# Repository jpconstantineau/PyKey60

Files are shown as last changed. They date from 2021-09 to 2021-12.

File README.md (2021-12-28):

# PyKey60 - Keyboard Hardware supported by the PyKey60 CircuitPython Download

### PyKey60: 60% Keyboard

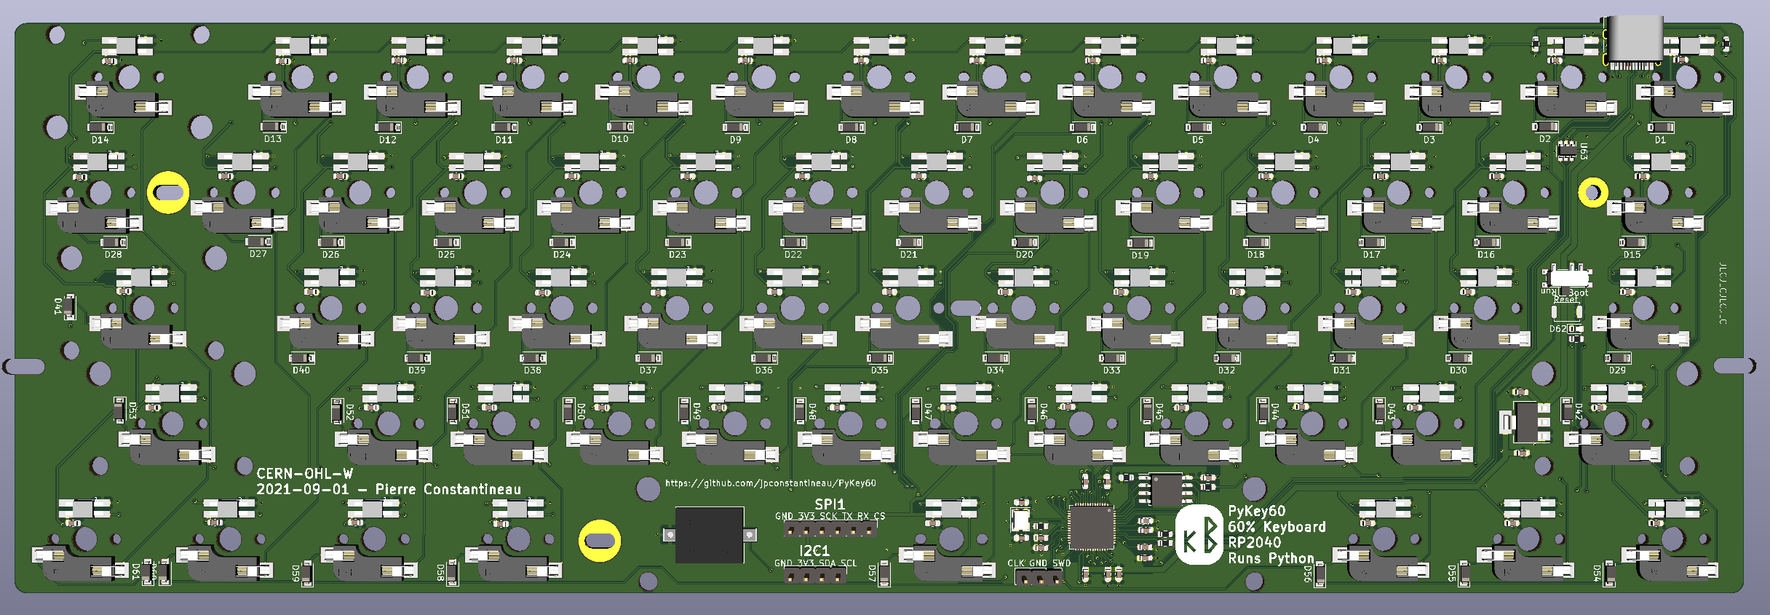
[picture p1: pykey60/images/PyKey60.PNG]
PyKey60


The PyKey60 is a custom programmable mechanical keyboard with a standard ANSI 60% keyboard layout compatible with any cases made for the GH60. The PyKey60 uses mechanical switches (Cherry MX type). The keys are hot-swap socketed and have an individual underglow RGB LED which can be turned on. The PCB was designed for use with PCB-mount stabilizers.

Since this is a Hot Swappable Switches keyboard, you can choose the MX switches as well as the keycaps you prefer. You can even mix and match switches for the ultimate customization.

Just like CircuitPython, this keyboard is targeted for beginners. The design keeps the matrix definition simple to 14 columns and 5 rows instead of using a GPIO-optimized matrix of 8 columns and 8 rows. Neopixel order is also in line with key numbers. This keeps the complexity of coding a keyboard firmware to a minimum.

[KMK Firmware](https://github.com/KMKfw/kmk_firmware/tree/master/boards/jpconstantineau/PyKey60)

Design of PyKey60 is licensed under **CERN Open Hardware Licence Version 2 - Weakly Reciprocal**

Author of the Pykey60 is Pierre Constantineau

### VColChoc44 (Atreus44)

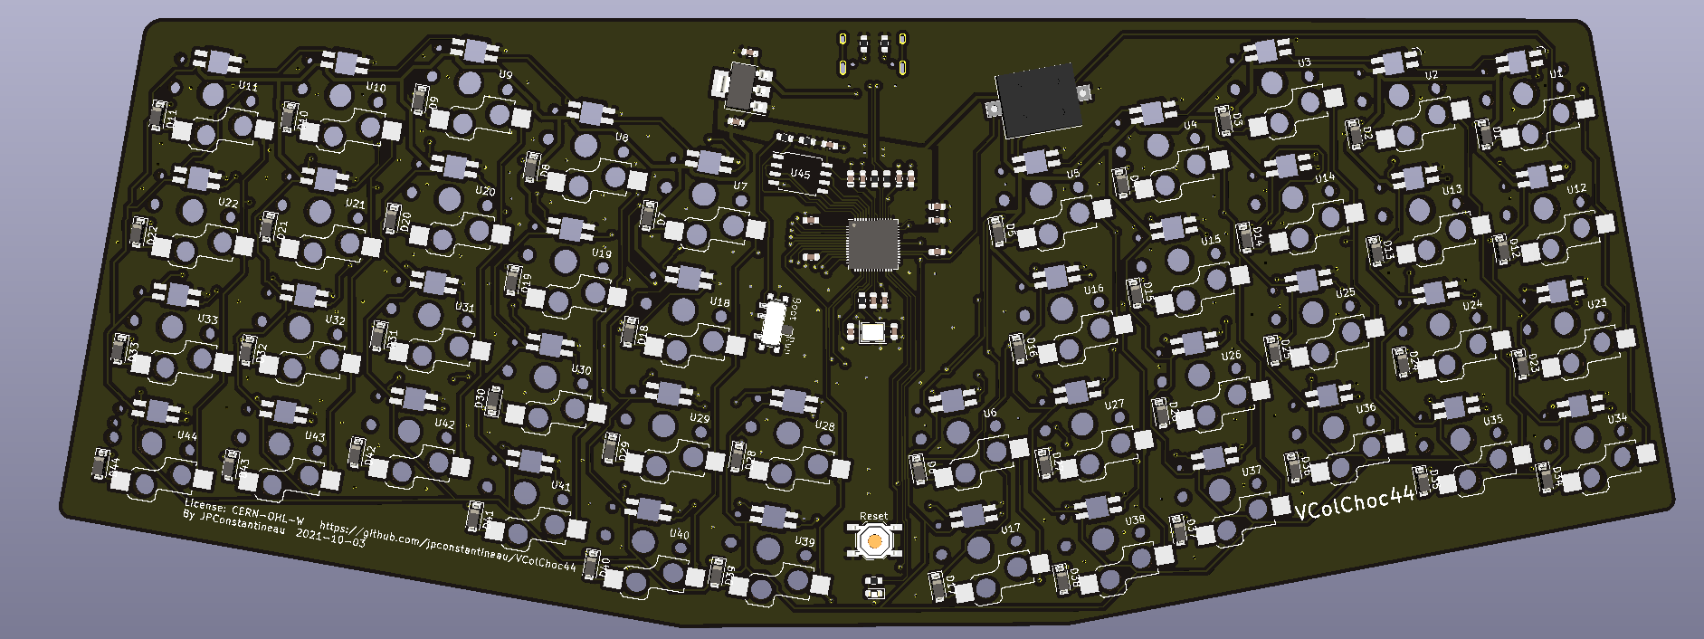
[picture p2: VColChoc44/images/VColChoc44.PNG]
VColChoc44


The VColChoc44 is a custom programmable mechanical keyboard with a 44-keys ergonomic keyboard layout. The VColChoc44 uses low profile mechanical switches (Kailh Choc V1 type). The keys are hot-swap socketed and have an individual underglow RGB LED which can be turned on.

The rows and columns used by VColChoc44 are a subset of PyKey60.

Design of VColChoc44 is licensed under **CERN Open Hardware Licence Version 2 - Weakly Reciprocal**

Author of the VColChoc44 is Pierre Constantineau

### PyKey87: TKL (Ten Key Less) Keyboard

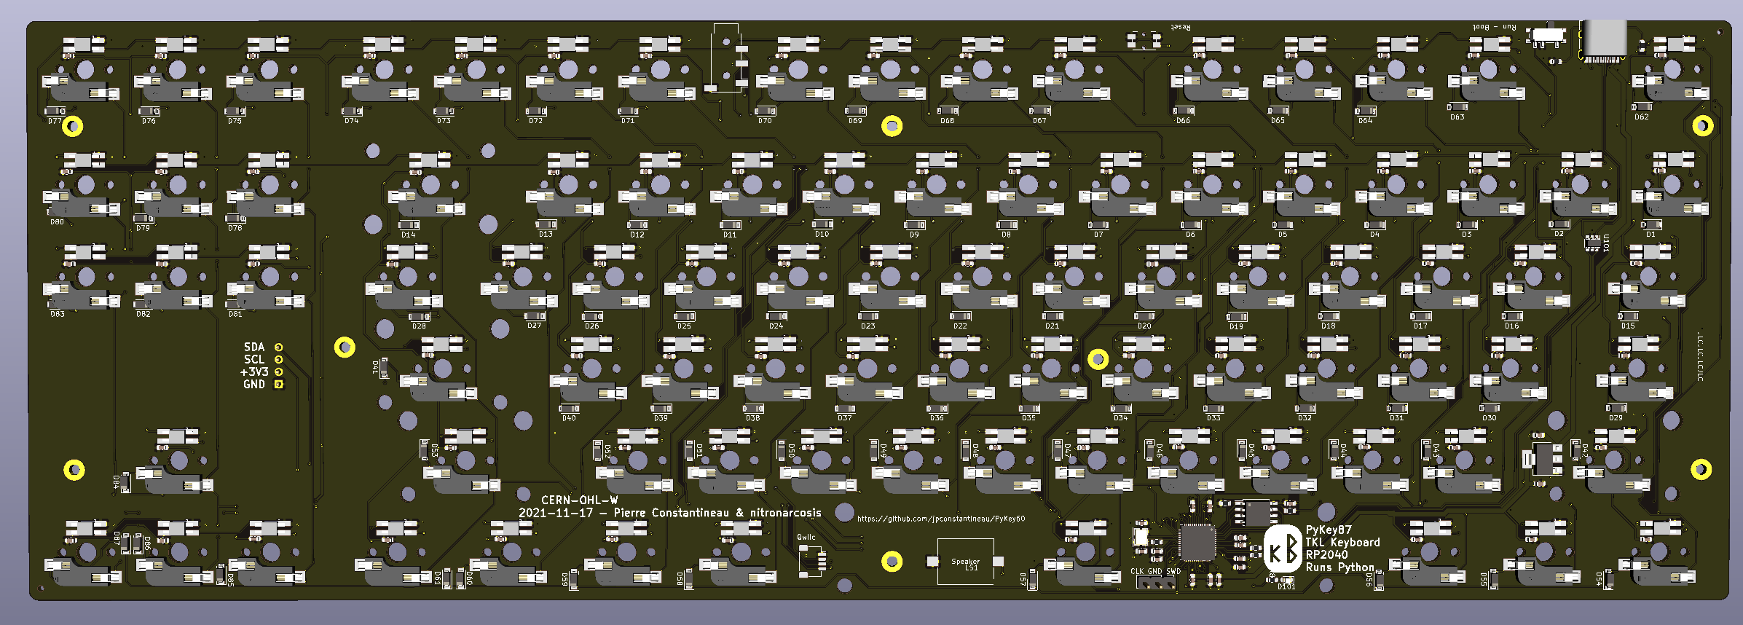
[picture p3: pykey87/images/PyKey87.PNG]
PyKey87


The PyKey87 is a custom programmable mechanical keyboard with a standard ANSI TKL (Ten Key Less) keyboard layout. The PyKey87 uses mechanical switches (Cherry MX type). The keys are hot-swap socketed and have an individual underglow RGB LED which can be turned on. The PCB was designed for use with PCB-mount stabilizers.  The case is a simple sandwich case.

The design keeps the matrix definition simple to 17 columns and 6 rows.

The rows and columns used by PyKey87 expanded the PyKey60 configuration to support more rows and columns.  The SPI pins were re-used for the additional columns/row.

Design of PyKey87 is licensed under **CERN Open Hardware Licence Version 2 - Weakly Reciprocal**

Authors of the Pykey87 are Pierre Constantineau and nitronarcosis (https://github.com/nitronarcosis)

### PyKey18: Numpad

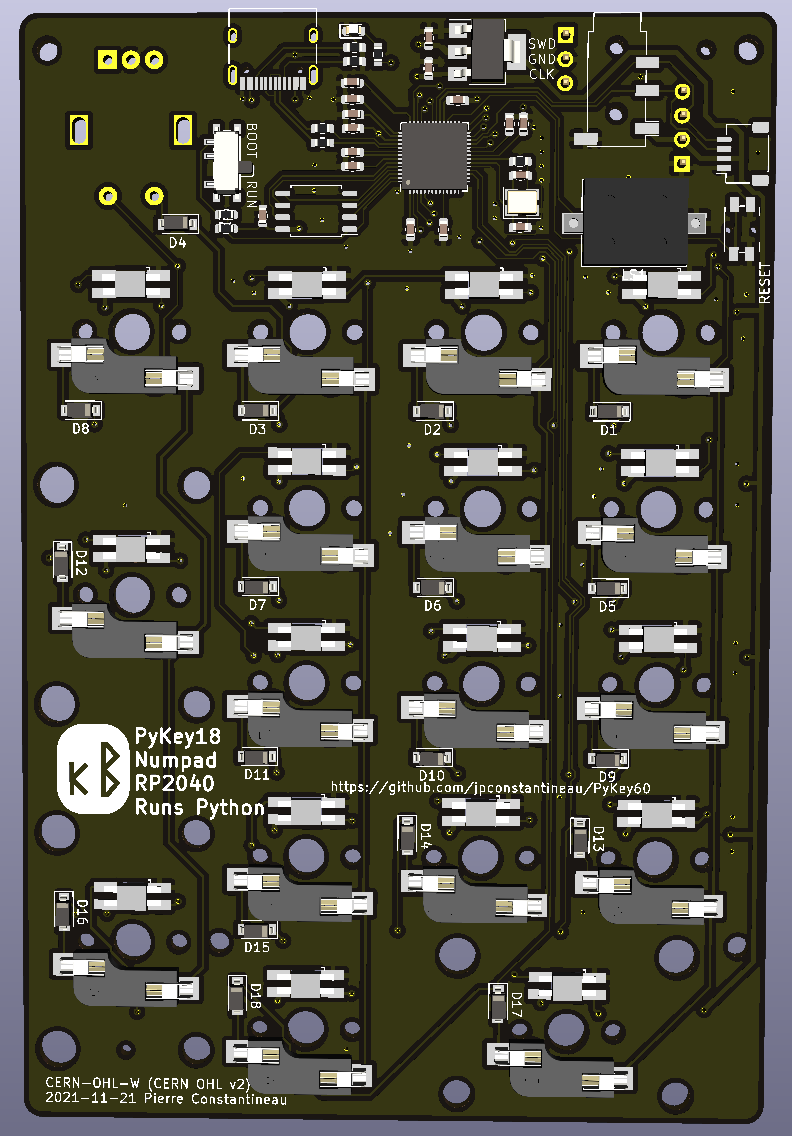
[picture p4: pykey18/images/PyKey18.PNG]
PyKey18

The PyKey18 is a custom programmable mechanical keyboard with a standard numpad keyboard layout.  The PyKey18 uses mechanical switches (Cherry MX type). The keys are hot-swap socketed and have an individual underglow RGB LED which can be turned on. The PCB was designed for use with PCB-mount stabilizers.  The case is a simple sandwich case. 

In addition to the standard numpad, it allows for a rotary encoder as well as a 0.91" OLED screen.  As such,  it can be used similarly to the Adafruit Macropad RP2040 but has more keys.

### Guidelines for adding new boards to PyKey60 repository

* Schematic must be compatible with the original Pykey60.  This means the following:
  * GPIO for Rows and Columns must remain the same
  * GPIO for RGB LEDs, Red LED and Speaker must remain the same
  * Flash chip must remain the same: W25Q128JVS
  * Schematic title block updated with correct information
    * Author(s)
    * Date
* Schematic is provided as a pdf file
* PCB Design has updated author(s) and date.
* PCB Design keeps the license label.
* Images provided in the image folder
* Both PCB-Design and PCB-Gerbers are provided.
* A readme is included
* CircuitPython must be able to run with the Original [PyKey60 CircuitPython Download/UF2](https://circuitpython.org/board/jpconstantineau_pykey60/) or the Pykey87 for larger keyboards.
* A summary description is provided in the repository readme

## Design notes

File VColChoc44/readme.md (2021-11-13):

# VColChoc44

### What is VColChoc44?

VColChoc44

### How do I build it?

You don't need many tools to build it!  
* Press the switches through the top plate
* Align the key switch pins with their sockets and press them in, 
* Install the keycaps
* Install the adhesive rubber bump ons as feet.

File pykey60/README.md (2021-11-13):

# PyKey60

### What is PyKey60?

PyKey60

### How do I build it?

You don't need many tools to build it!  
* Press the switches through the top plate
* Align the key switch pins with their sockets and press them in, 
* Install the keycaps
* Install the adhesive rubber bump ons as feet.

### How do I program it?

PyKey60 can be programmed with CircuitPython.  To get started, get the latest download from the official [CircuitPython.org](https://circuitpython.org/) site, put the RP2040 in  booloader mode by pressing "reset" while pressing the "boot" button and drag/drop in the UF2 file you just downloaded. You are now ready to program it! No build tools required on your computer!

Notes: 
* CircuitPython is licensed under the [MIT License](https://github.com/adafruit/circuitpython/blob/main/LICENSE).
* Default Firmware for PyKey60 is based on the [MACROPAD Hoykeys](https://learn.adafruit.com/macropad-hotkeys) example for the [Adafruit Macropad RP2040](https://learn.adafruit.com/adafruit-macropad-rp2040) which is part of the [Adafruit Learning System Guides](https://learn.adafruit.com/), licensed under the [MIT License](https://github.com/adafruit/Adafruit_Learning_System_Guides/blob/main/LICENSE).
* Default firmware is **MIT** licensed.

### Hardware License

Design of PyKey60 is licensed under **CERN Open Hardware Licence Version 2 - Weakly Reciprocal**

See license.txt for more details. See this [FAQ](https://ohwr.org/project/cernohl/wikis/faq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) for more information on this license.

### Licenses from reference material and libraries

|  Item  | Description | Source  | License  |
|----|---- | :-----  | :--- |
| RP2040 Hardware Design Guide  | RP2040 Documentation (for reference) | [link](https://datasheets.raspberrypi.org/rp2040/hardware-design-with-rp2040.pdf) | CC BY-ND |
| RP2040 Minimal Design Example | Kicad Project | [link](https://datasheets.raspberrypi.org/rp2040/Minimal-KiCAD.zip) | 3-Clause BSD (considered as source code included as part of documentation) |
| kicad libraries | Core libraries from Kicad | [link](https://www.kicad.org/libraries/license/) | CC-BY-SA 4.0 (with exception)|
| kicad libraries | switch symbols and footprints | [link](https://github.com/sszczep/kicad-libraries)| MIT | 

### openmoko-usb-oui application details

[USB PID Request](https://github.com/openmoko/openmoko-usb-oui)

1. () Have a README[.txt|.md] file describing which part is under which license this will help to quickly identify the project's license, particularly when several licenses are combined, or your are using libraries under other licenses. Also make sure the combination is allowed by the individual licenses.
2. (done) Include all full text licenses in a LICENSE[.txt] file
3. () Include a copyright notice in the schematic sheet(s), including author and date this will determine who the copyright holder is, and when the copyright will expire.
4. () Include the license name in the schematic sheet(s) this becomes important when different license are combined, and parts of the project, or libraries, are under different licenses
5. () Include all schematic symbols and board footprint libraries in the project without that the project can't be seen as complete. Also ensure their license is compatible.
66. () Export the schematic capture as pdf, and board layout as gerber+NC drill [and other fabrication output] files - not every user can, or wants, to install the EDA suite you are using. This is even more important if in the future this suite stops supporting the current format. If you don't want to mix the fabrication output with the source files, have a general project page pointing to the source files and fabrication output.

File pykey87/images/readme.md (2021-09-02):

These svg images were generated using the gerbers and [Tracespace View](https://tracespace.io/view/) an online gerver viewer and are for reference.

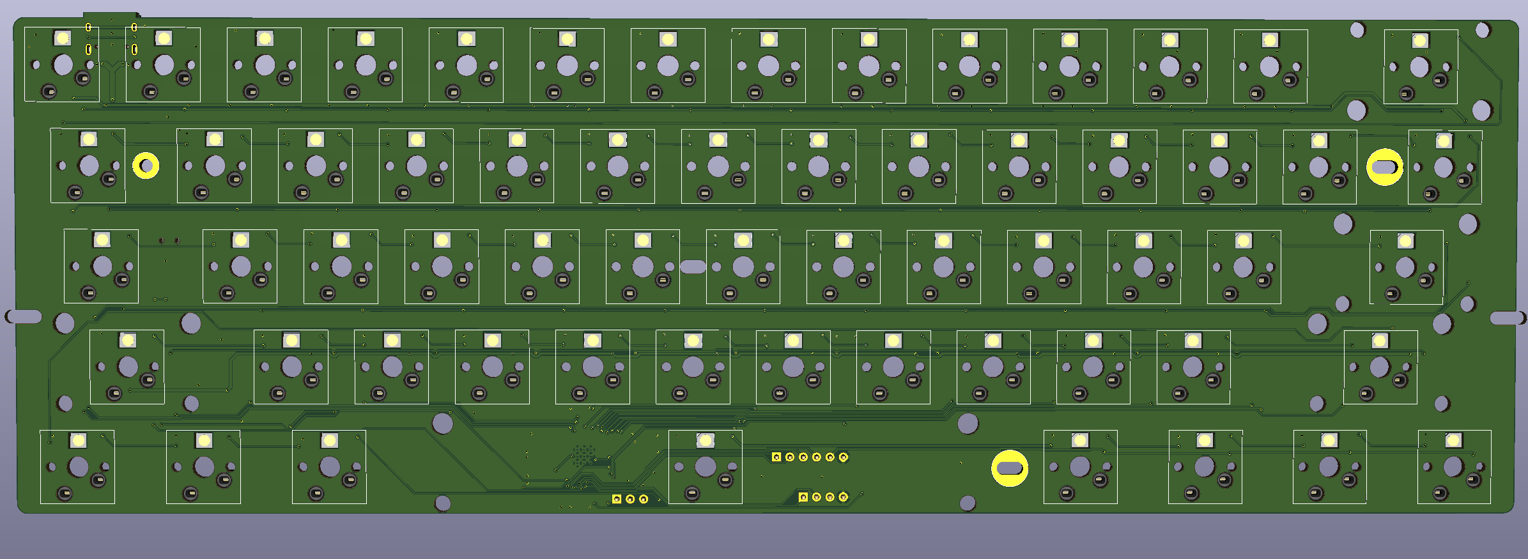
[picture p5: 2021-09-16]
pykey60/images/PCB-Front.PNG

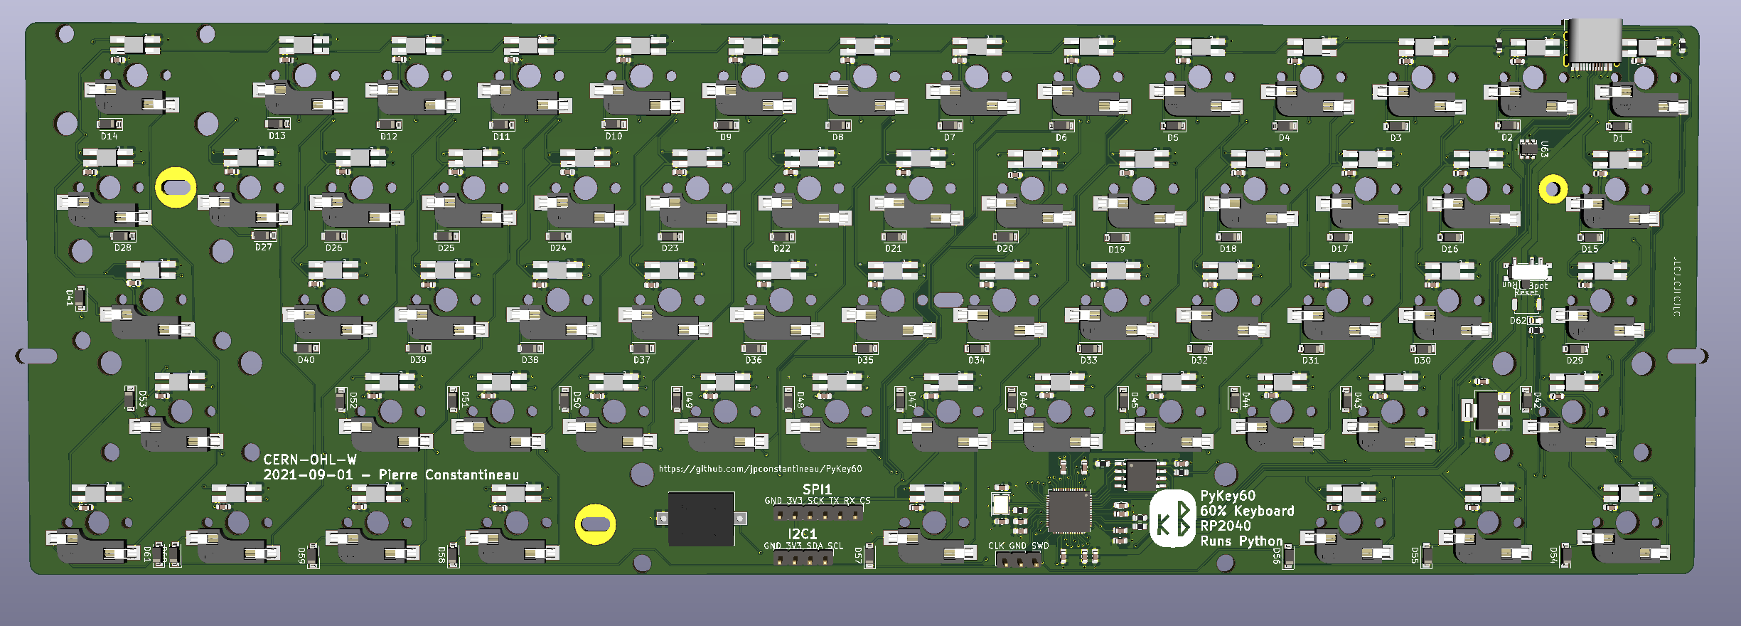
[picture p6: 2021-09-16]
pykey60/images/PCB-Back.PNG

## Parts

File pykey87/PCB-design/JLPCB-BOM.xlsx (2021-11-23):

Comment | Designator | Footprint | JLCPCB Part #
1k | R8,R7,R5 | R_0603_1608Metric | C21190
RED | D101 | LED_0603_1608Metric | C2286
100n | C9,C87,C86,C85,C84,C82,C79,C81,C83,C80,C78,C77,C76,C75,C74,C73,C72,C71,C70,C69,C68,C67,C66,C64,C65,C63,C62,C15,C23,C24,C11,C35,C10,C14,C22,C12,C21,C34,C36,C13,C19,C3,C32,C20,C37,C38,C8,C47,C4,C18,C33,C25,C48,C49,C7,C45,C2,C17,C46,C26,C50,C57,C1,C29,C5,C27,C44,C53,C39,C51,C6,C55,C61,C43,C41,C58,C59,C16,C28,C41,C60,C52,C30,C54,C40,C31,C56,C101,C96,C95,C94,C93,C92,C91,C90,C89,C88 | C_0603_1608Metric | C14663
D | D87,D86,D85,D84,D83,D82,D81,D80,D79,D78,D77,D76,D75,D74,D73,D72,D71,D70,D69,D68,D67,D66,D65,D64,D63,D62,D61,D60,D59,D58,D57,D56,D55,D54,D53,D52,D51,D50,D49,D48,D47,D46,D45,D44,D43,D42,D41,D40,D39,D38,D37,D36,D35,D34,D33,D32,D31,D30,D29,D28,D27,D26,D25,D24,D23,D22,D21,D20,D19,D18,D17,D16,D15,D14,D13,D12,D11,D10,D9,D8,D7,D6,D5,D4,D3,D2,D1 | D_SOD-123 | C81598
AMS1117-3.3 | U103 | SOT-223-3_TabPin2 | C6186
22u | C103,C102 | C_0603_1608Metric | C12891
12MHz | Y1 | Crystal_SMD_3225-4Pin_3.2x2.5mm | C9002
22 | R4,R3 | R_0603_1608Metric | C23345
22p | C100,C99 | C_0603_1608Metric | C1653
1u | C98,C97 | C_0603_1608Metric | C15849
USB_C_Receptacle_USB2.0 | J1 | USB_C_Receptacle_HRO_TYPE-C-31-M-12 | C165948
5.1k | R1,R2 | R_0603_1608Metric | C23186
RP2040 | U100 | RP2040-QFN-56 | C2040
USBLC6-2SC6 | U101 | SOT-23-6 | C2827654
W25Q128JVS | U102 | SOIC-8_5.23x5.23mm_P1.27mm | C97521
SW_SPDT | SW2 | SW_SPDT_PCM12 | C221841

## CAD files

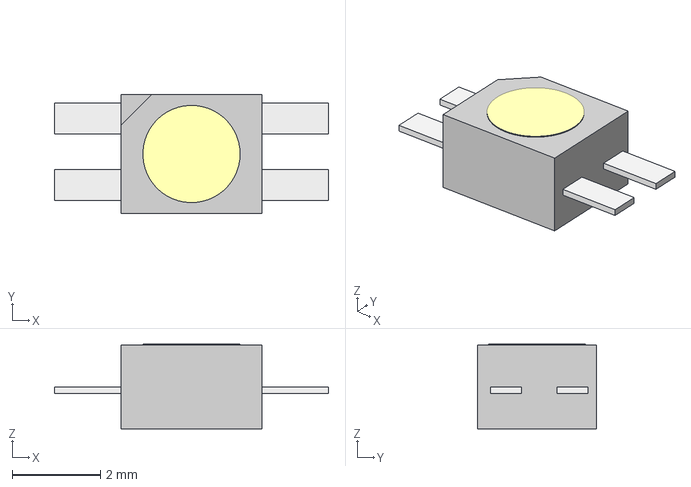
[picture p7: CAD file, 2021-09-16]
pykey18/bottom-plate/PyKey18/models/LTST-A683CEGBW.step
6.20 x 2.70 x 1.92 mm

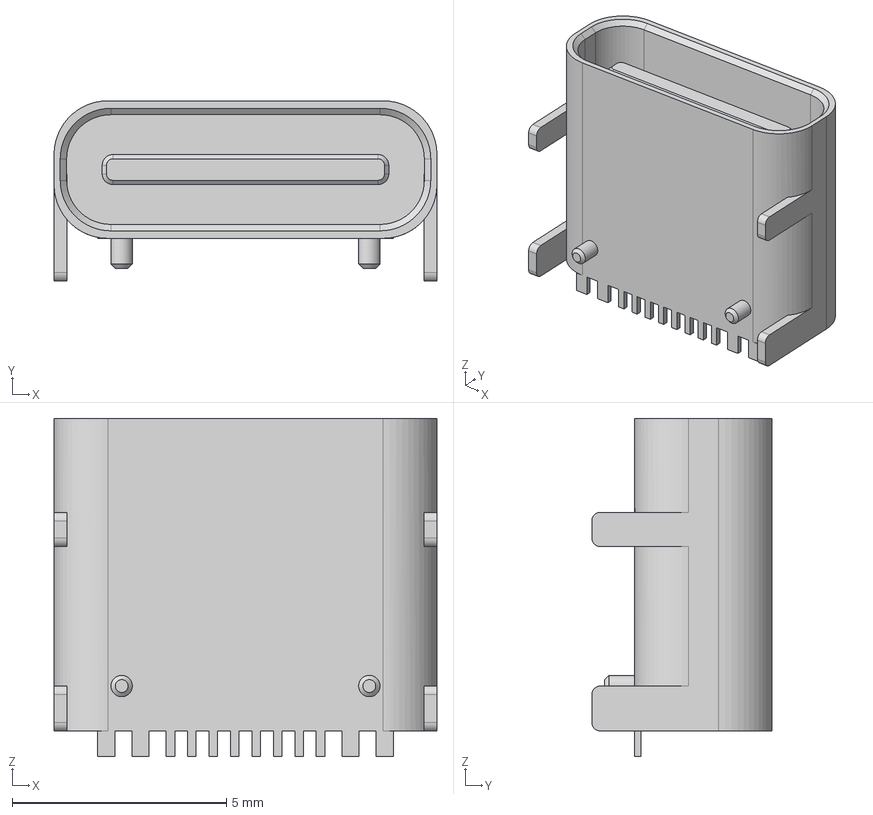
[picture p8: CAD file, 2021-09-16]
pykey18/bottom-plate/PyKey18/models/HRO TYPE-C-31-M-12.step
8.94 x 4.21 x 7.90 mm

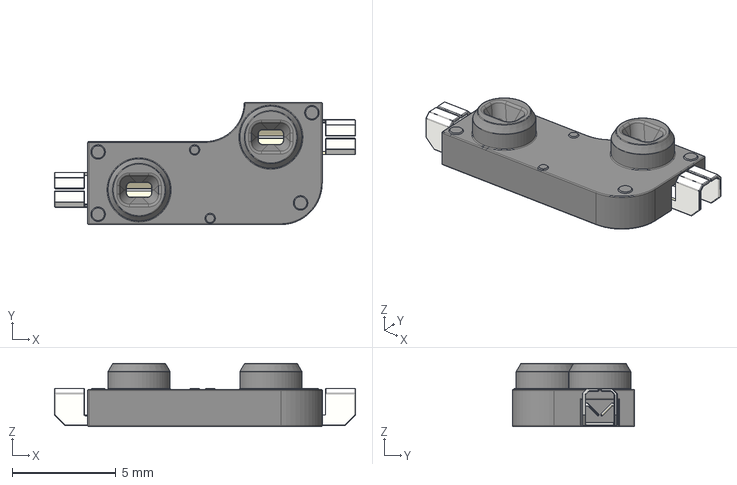
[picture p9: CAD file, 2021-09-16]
pykey18/switch-plate/PyKey18/models/KailhSocket.stp
14.5 x 5.89 x 3.05 mm

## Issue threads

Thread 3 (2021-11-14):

Add TKL Board: PyKey87

jpconstantineau, 2021-11-14:
Proposed changes:

## Schematic:
* ~~Add connector for OLED (currently not linked to schematic)~~
* ~~Add text to indicate difference between OLED and Qwiic connectors~~
* ~~Add mounting holes (JLCPCB tooling holes) (currently not linked to schematic)~~
* ~~Add TRRS connector for supporting separate numpad through I2C. Use:~~
    * Symbol: Connector:AudioJack4
    * footprint: Connectors:PJ320D_3.5mm_Jack
    * T - VCC
    * S - GND
* ~~Update date in title block~~

## PCB:
* ~~Move LED and resistor near the bottom (below the KB logo)~~
* ~~Move Run/Boot text on silkscreen near slider switch~~
* ~~Move reset text on silkscreen near reset switch~~
* ~~Label JST connector with "Qwiic"  (We can't label it Stemma as we don't support 5V).  The official logo can be used.~~
* ~~Label pins of OLED connector on back side~~
* ~~Hide labels U62-U87 on top side of PCB~~
* ~~Position new TRRS connector in line with OLED near the right edge (on the bottom side.)~~

### Stemma QT vs Qwiic
https://www.sparkfun.com/qwiic
https://learn.adafruit.com/introducing-adafruit-stemma-qt/technical-specs

@nitronarcosis

jpconstantineau, 2021-11-14:
Updates:

Getting this error message:
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

jpconstantineau, 2021-11-18:
## PCB
Diodes D62 to D77 have a similar (but easier to solve) clearance issue
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

##Schematic
There are 3 schematic symbols that are in the rescue symbol libraries.  They should point to the correct libraries so that the rescue one can be deleted.

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

USBLC602SC6 should be Power_Protection:USBLC6-2SC6e
USB_C_Receptable_USB2 should be Connector:USB_C_Receptacle_USB2.0
W25Q128JVS should be Memory_Flash:W25Q128JVS

jpconstantineau, 2021-11-18:
Useful app for checking gerbers: https://tracespace.io/view/

jpconstantineau, 2021-11-18:
## Switch Plate:

Big hole is on the side of the wire: see here:
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

## Schematic
Delete PyKey87-rescue.lib and PyKey87-rescue.dcm as they are no longer needed.

jpconstantineau, 2021-11-20:
## Schematic

* Remove reference to rescue library in project preferences:

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

Closed 2021-11-23.

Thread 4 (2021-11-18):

Add Numpad Board: PyKey18

jpconstantineau, 2021-11-18:
* RP2040 on board
* TRRS to connect to PyKey87
* OLED
* Rotary Encoder  - 1 key
* Standard Numpad layout
* Per-key RGB
* Hot Swap Sockets
* Same height as PyKey87
* Feet positions: same distance from bottom
* Standard numpad layout as per http://www.keyboard-layout-editor.com/  17 keys
* Use GPIO 27/28 for EncA/B

nitronarcosis, 2021-11-23:
I'm a little wary of running speaker in parallel to reset but that's probably not a big deal because any induced current will drive it high, not low.
I also don't see any decoupling capacitors on the LEDs.
Is there ESD protection? I'm not seeing that either.

jpconstantineau, 2021-11-24:
Added a grounded line between most of the Reset and Speaker lines
Added caps
Added ESD protection.

Closed 2021-11-23.

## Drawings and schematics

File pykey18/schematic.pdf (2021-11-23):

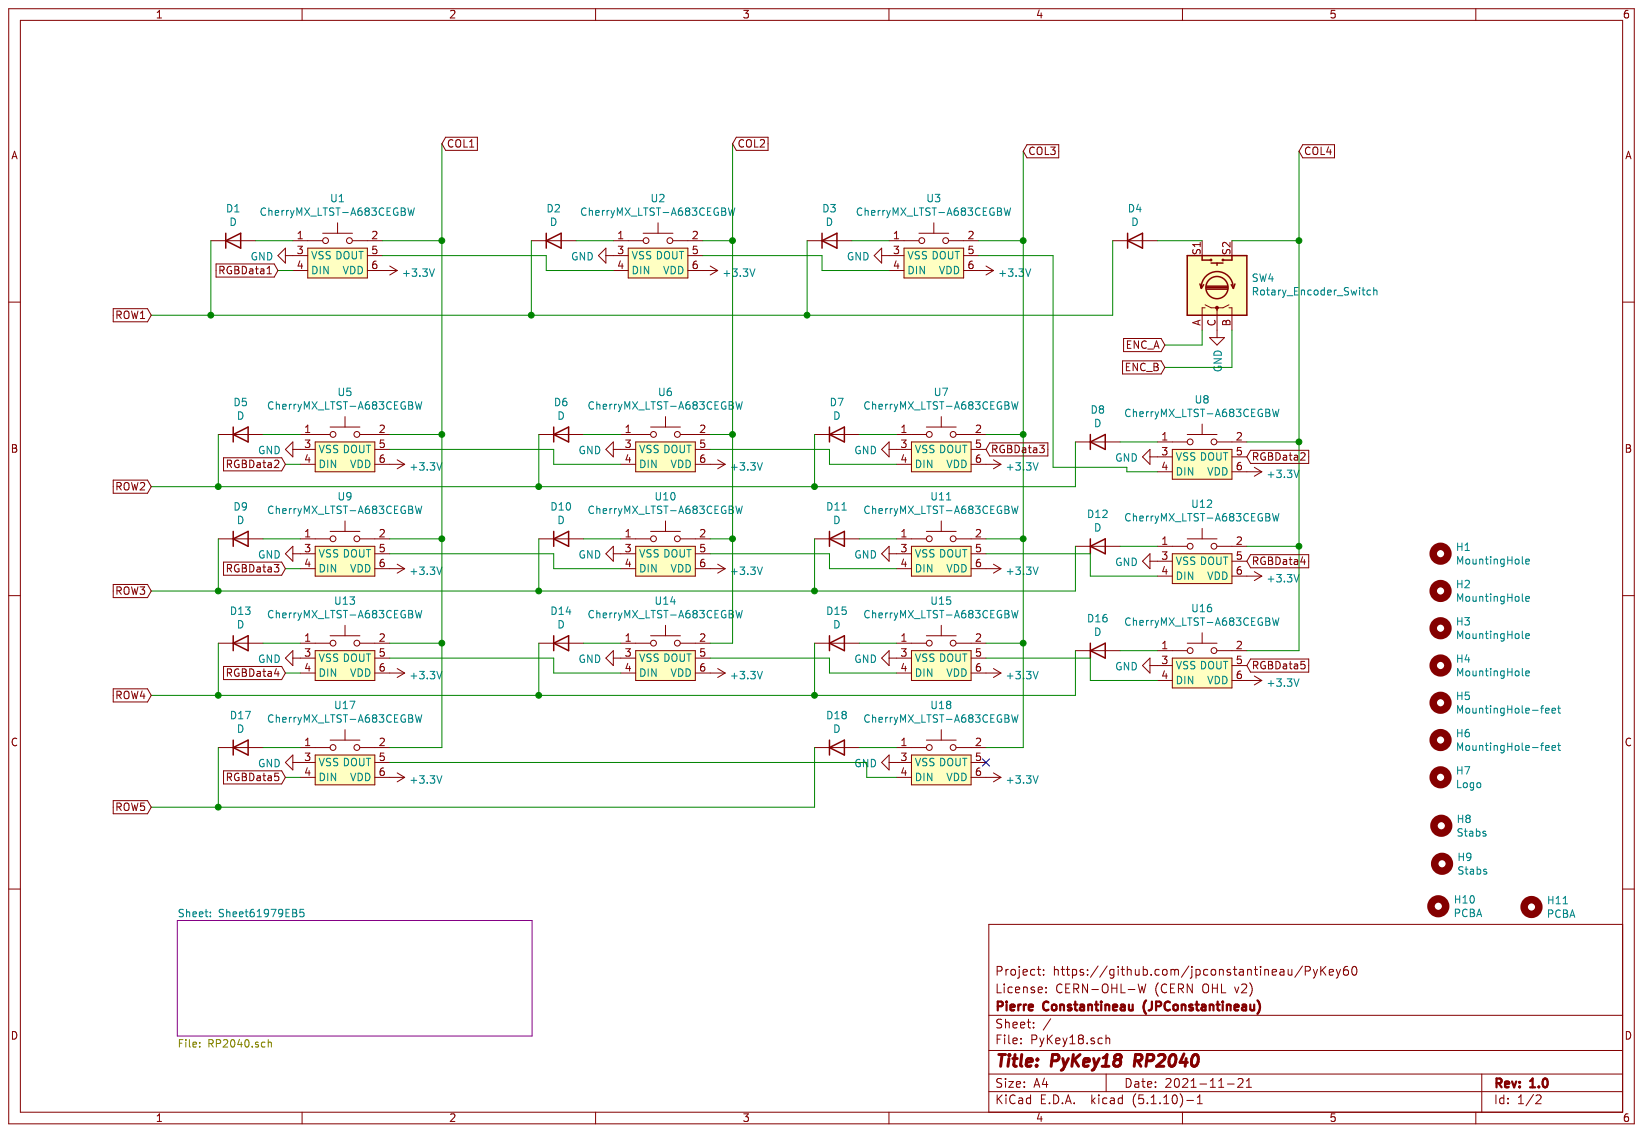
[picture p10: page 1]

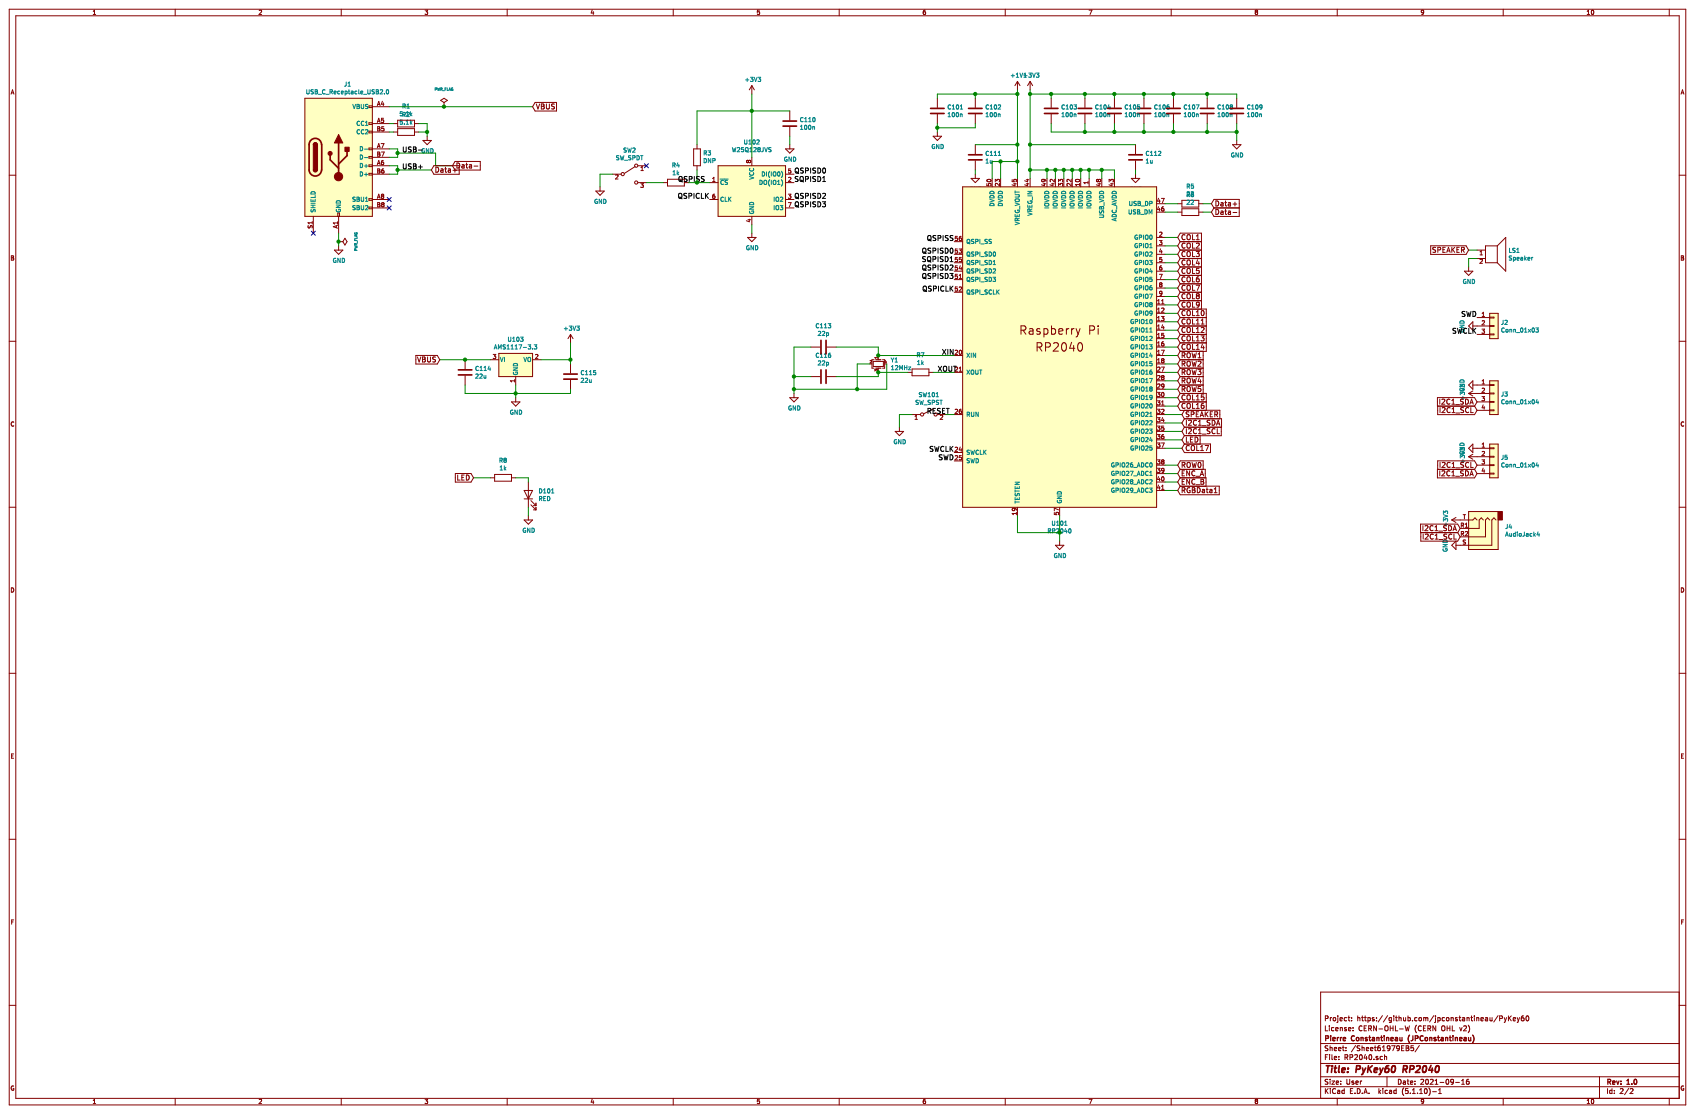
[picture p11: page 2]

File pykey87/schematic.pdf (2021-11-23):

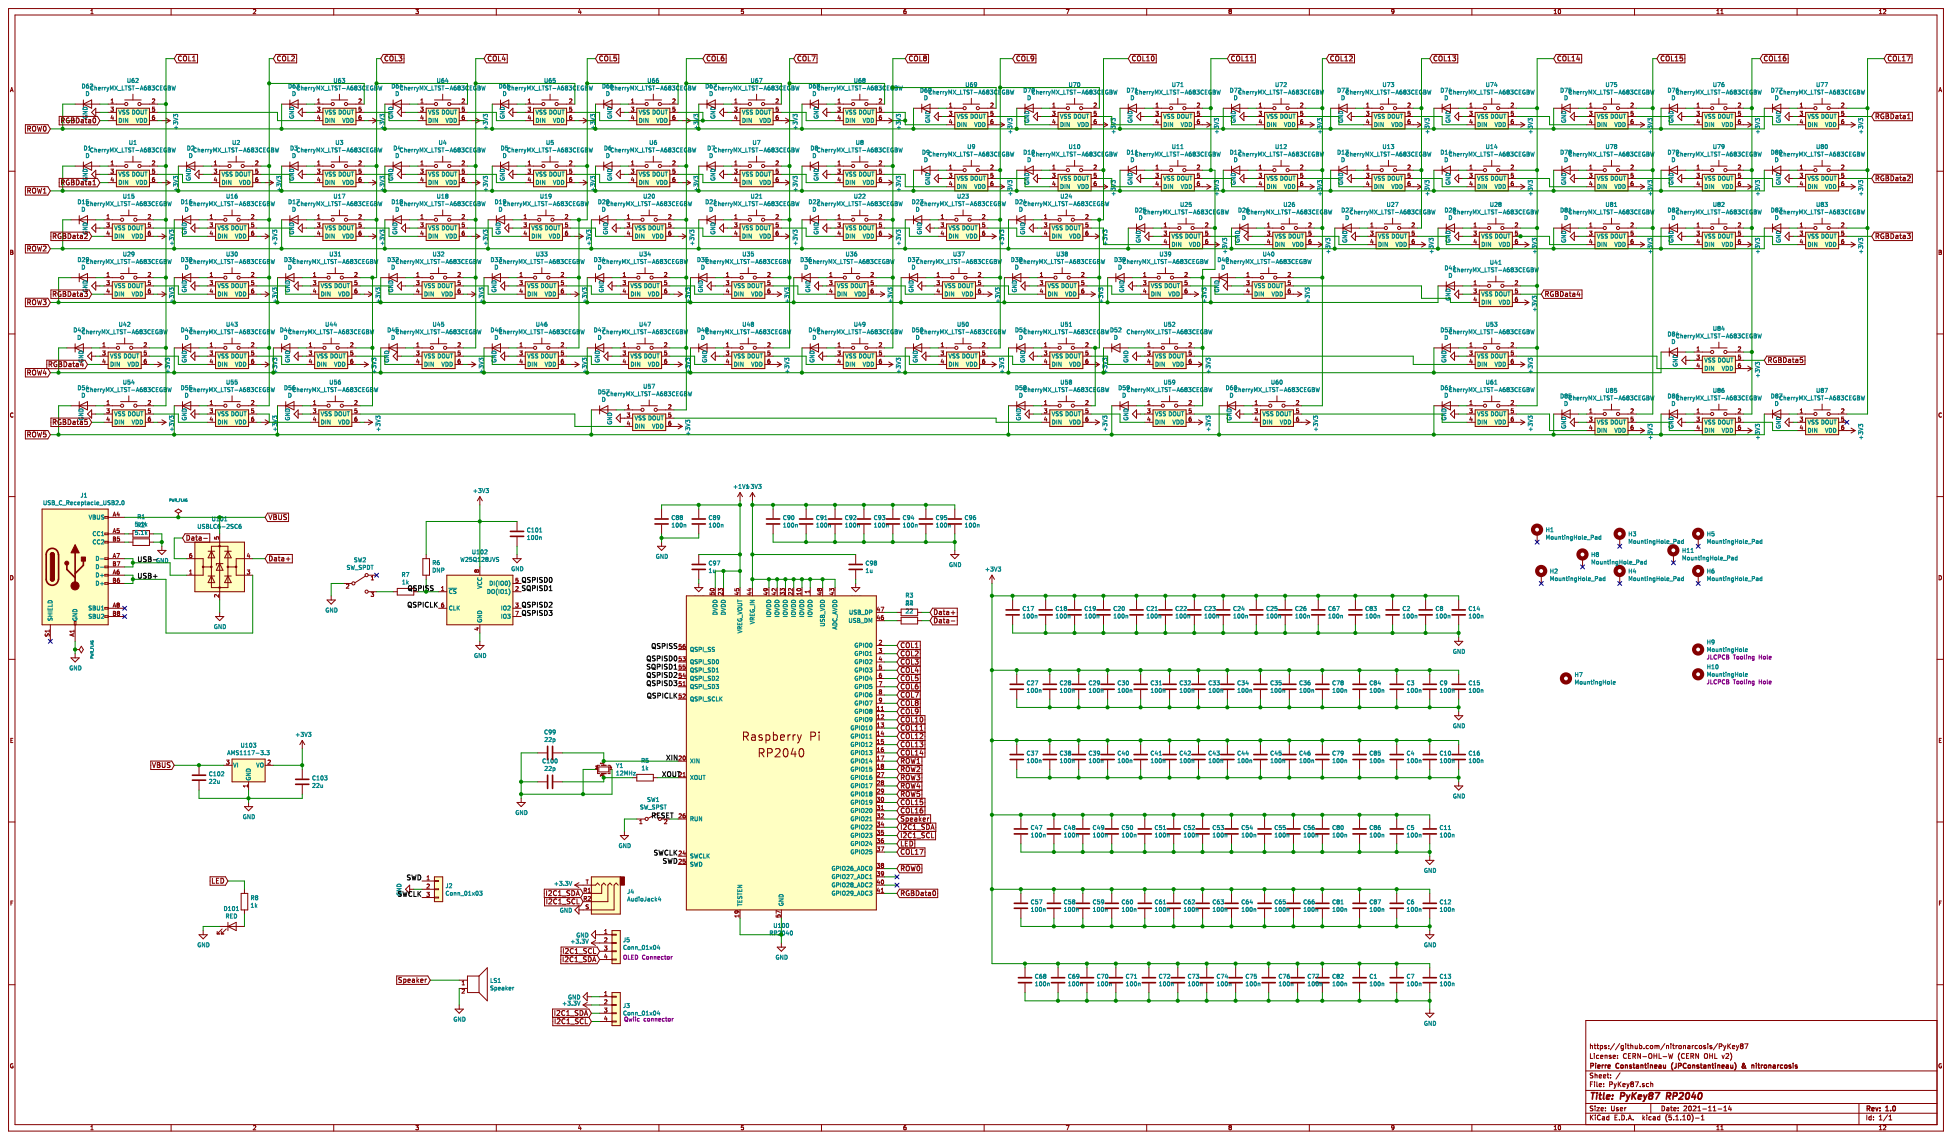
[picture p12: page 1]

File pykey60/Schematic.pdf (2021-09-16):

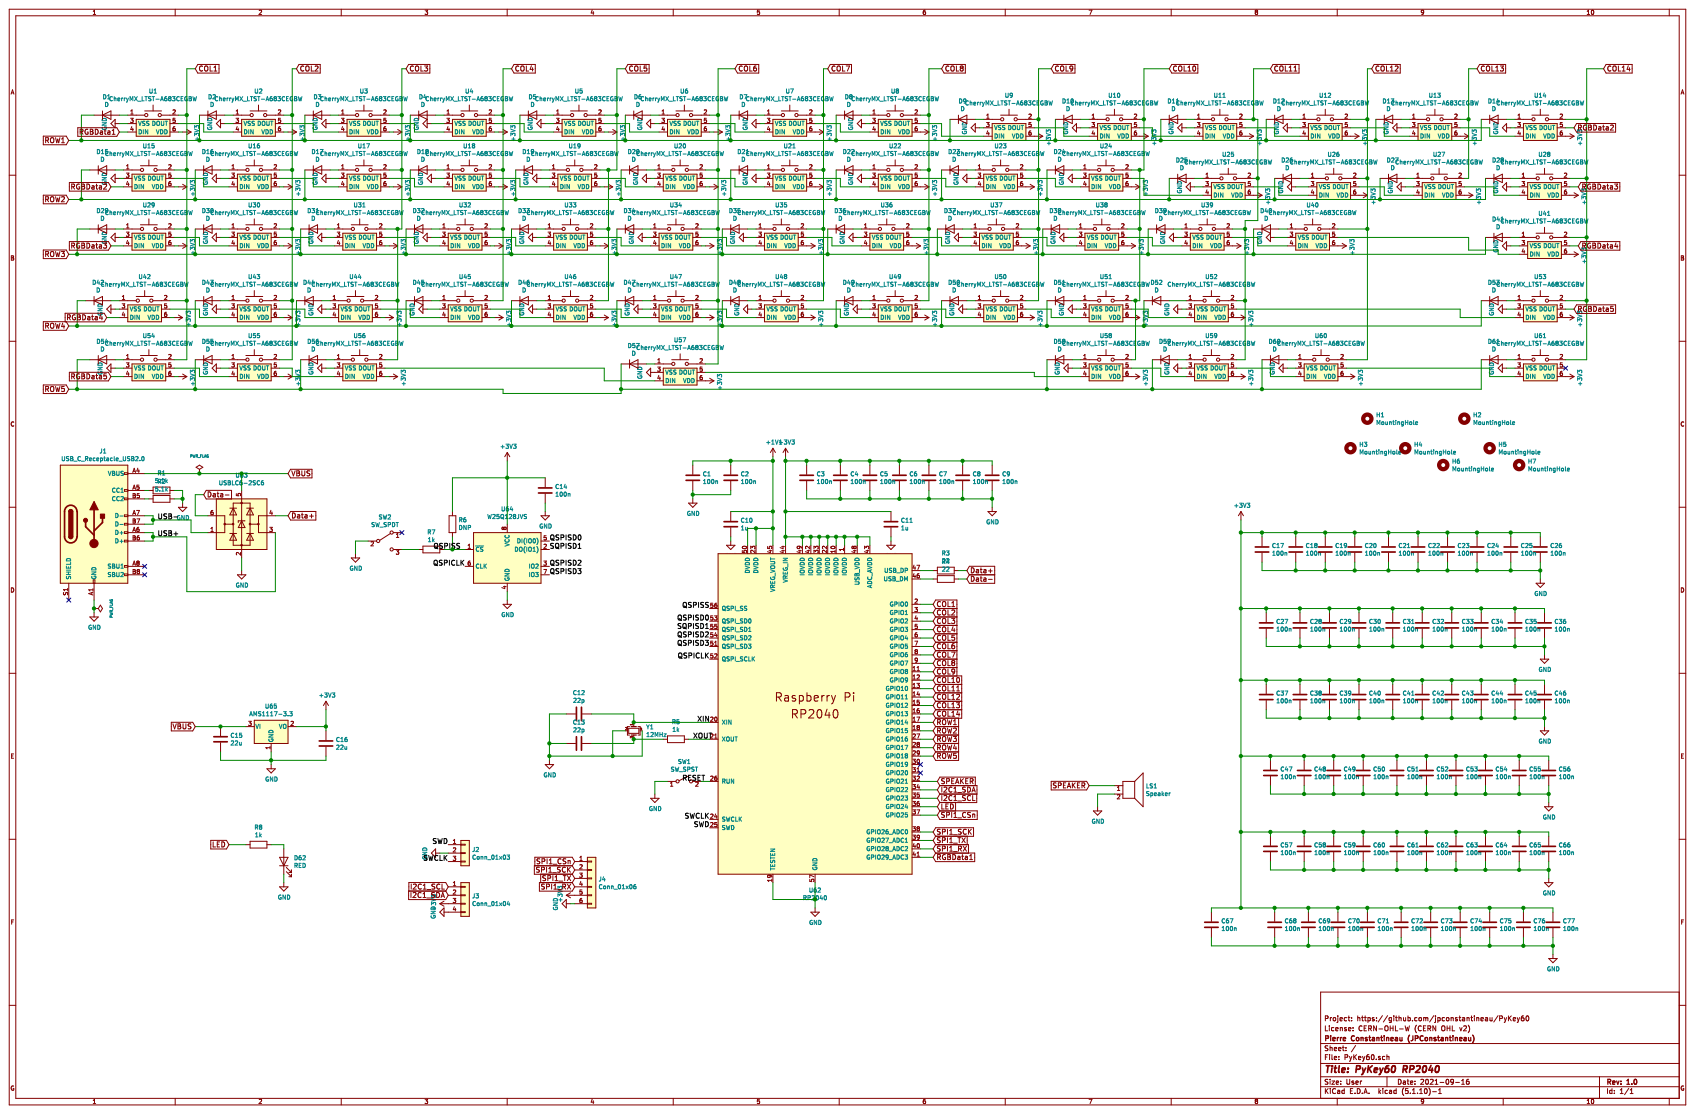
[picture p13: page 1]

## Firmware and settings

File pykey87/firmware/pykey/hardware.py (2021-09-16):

# SPDX-FileCopyrightText: Copyright (c) 2021 Pierre Constantineau
#
# SPDX-License-Identifier: MIT
"""
`jpconstantineau_pykey`
================================================================================
A helper library for hardware keyboards
* Author(s): Pierre Constantineau

Implementation Notes
--------------------
**Hardware:**


**Software and Dependencies:**

* Adafruit CircuitPython firmware for the supported boards:
  https://circuitpython.org/downloads

* Adafruit's CircuitPython NeoPixel library:
  https://github.com/adafruit/Adafruit_CircuitPython_NeoPixel

* Adafruit's CircuitPython HID library:
  https://github.com/adafruit/Adafruit_CircuitPython_HID

"""

import os
import usb_hid
from adafruit_hid.keyboard import Keyboard

class PK_Hardware:
    """
    Class representing a keyboard Hardware without the specifics...
    """

    def __init__(self):


        self._board_type = os.uname().machine
        self._keyboard = None
        self._pixels = None
        self._leds = None
        self._speaker =  None


    @property
    def keys(self):
        """
        The keys on the MacroPad. Uses events to track key number and state, e.g. pressed or
        released. You must fetch the events using ``keys.events.get()`` and then the events are
        available for usage in your code. Each event has three properties:
        * ``key_number``: the number of the key that changed. Keys are numbered starting at 0.
        * ``pressed``: ``True`` if the event is a transition from released to pressed.
        * ``released``: ``True`` if the event is a transition from pressed to released.
                        ``released`` is always the opposite of ``pressed``; it's provided
                        for convenience and clarity, in case you want to test for
                        key-release events explicitly.
        The following example prints the key press and release events to the serial console.
        .. code-block:: python
            from adafruit_macropad import MacroPad
            macropad = MacroPad()
            while True:
                key_event = macropad.keys.events.get()
                if key_event:
                    print(key_event)
        """
        return self._keys

    @property
    def encoder(self):
        """
        The rotary encoder relative rotation position. Always begins at 0 when the code is run, so
        the value returned is relative to the initial location.
        The following example prints the relative position to the serial console.
        .. code-block:: python
            from adafruit_macropad import MacroPad
            macropad = MacroPad()
            while True:
                print(macropad.encoder)
        """
        return self._encoder.position

    @property
    def speaker(self):
        return self._speaker

    @property
    def leds(self):
        return self._leds

    @property
    def pixels(self):
        """Sequence-like object representing the twelve NeoPixel LEDs in a 3 x 4 grid on the
        MacroPad. Each pixel is at a certain index in the sequence, numbered 0-11. Colors can be an
        RGB tuple like (255, 0, 0) where (R, G, B), or an RGB hex value like 0xFF0000 for red where
        each two digits are a color (0xRRGGBB). Set the global brightness using any number from 0
        to 1 to represent a percentage, i.e. 0.3 sets global brightness to 30%. Brightness defaults
        to 1.
        See ``neopixel.NeoPixel`` for more info.
        The following example turns all the pixels green at 50% brightness.
        .. code-block:: python
            from adafruit_macropad import MacroPad
            macropad = MacroPad()
            macropad.pixels.brightness = 0.5
            while True:
                macropad.pixels.fill((0, 255, 0))
        The following example sets the first pixel red and the twelfth pixel blue.
        .. code-block:: python
            from adafruit_macropad import MacroPad
            macropad = MacroPad()
            while True:
                macropad.pixels[0] = (255, 0, 0)
                macropad.pixels[11] = (0, 0, 255)
        """
        return self._pixels

    @property
    def keyboard(self):
        """
        A keyboard object used to send HID reports. For details, see the ``Keyboard`` documentation
        in CircuitPython HID: https://circuitpython.readthedocs.io/projects/hid/en/latest/index.html
        The following example types out the letter "a" when the rotary encoder switch is pressed.
        .. code-block:: python
            from adafruit_macropad import MacroPad
            macropad = MacroPad()
            while True:
                if macropad.encoder_switch:
                    macropad.keyboard.send(macropad.Keycode.A)
        """
        if self._keyboard is None:
            self._keyboard = Keyboard(usb_hid.devices)
        return self._keyboard

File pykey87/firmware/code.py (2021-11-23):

#pylint: disable = line-too-long
import os
import time
import board
import neopixel
import keypad
import usb_hid
from adafruit_hid.keyboard import Keyboard
from pykey.keycode import PK_Keycode as KC
from adafruit_hid.keyboard_layout_us import KeyboardLayoutUS

# Hardware definition: GPIO where RGB LED is connected.
pixel_pin = board.A3
num_pixels = 87
pixels = neopixel.NeoPixel(pixel_pin, num_pixels, brightness=0.3, auto_write=False)


# Hardware definition: Switch Matrix Setup.
keys = keypad.KeyMatrix(
    row_pins=(board.GP27, board.GP14, board.GP15, board.GP16, board.GP17, board.GP18),
    column_pins=(board.GP0, board.GP1, board.GP2, board.GP3, board.GP4, board.GP5, board.GP6,
                 board.GP7, board.GP8, board.GP9, board.GP10, board.GP11, board.GP12, board.GP13,
				 board.GP19, board.GP20, board.GP25),
    columns_to_anodes=True,
)


# CONFIGURABLES ------------------------

MACRO_FOLDER = '/layers'


# CLASSES AND FUNCTIONS ----------------

class Layer:
    """ Class representing a layer, for which we have a set
        of macro sequences or keycodes"""
    def __init__(self, layerdata):
        self.name = layerdata['name']
        self.macros = layerdata['macros']


# Neopixel update function
def update_pixels(color):
    for i in range(num_pixels):
        pixels[i] = color
    pixels.show()


# INITIALIZATION -----------------------

# Load all the macro key setups from .py files in MACRO_FOLDER
layers = []

files = os.listdir(MACRO_FOLDER)
files.sort()
for filename in files:
    print(filename)
    if filename.endswith('.py'):
        try:
            module = __import__(MACRO_FOLDER + '/' + filename[:-3])
            layers.append(Layer(module.layer))
        except (SyntaxError, ImportError, AttributeError, KeyError, NameError,
                IndexError, TypeError) as err:
            print(err)
            pass

if not layers:
    print('NO MACRO FILES FOUND')
    while True:
        pass

layer_count = len(layers)
# print(layer_count)

def get_active_layer(layer_keys_pressed, layer_count):
    tmp = 0
    if len(layer_keys_pressed)>0:
        for layer_id in layer_keys_pressed:
            if layer_id > tmp: # use highest layer number
                tmp = layer_id
    if tmp >= layer_count:
        tmp = layer_count-1
    return tmp


# setup variables
keyboard = Keyboard(usb_hid.devices)
keyboard_layout = KeyboardLayoutUS(keyboard)
active_keys = []
not_sleeping = True
layer_index = 0

while not_sleeping:
    key_event = keys.events.get()
    if key_event:
        key_number = key_event.key_number

        # keep track of keys being pressed for layer determination
        if key_event.pressed:
            active_keys.append(key_number)
        else:
            active_keys.remove(key_number)

        # reset the layers and identify which layer key is pressed.
        layer_keys_pressed = []
        for active_key in active_keys:
            group = layers[0].macros[active_key][2]
            for item in group:
                if isinstance(item, int):
                    if (item >= KC.LAYER_0) and (item <= KC.LAYER_F) :
                        layer_keys_pressed.append(item - KC.LAYER_0)
        layer_index = get_active_layer(layer_keys_pressed, layer_count)
        # print(layer_index)
        # print(layers[layer_index].macros[key_number][1])
        group = layers[layer_index].macros[key_number][2]
        color = layers[layer_index].macros[key_number][0]
        if key_event.pressed:
            update_pixels(color)
            for item in group:
                if isinstance(item, int):
                    keyboard.press(item)
                else:
                    keyboard_layout.write(item)
        else:
            for item in group:
                if isinstance(item, int):
                    if item >= 0:
                        keyboard.release(item)
            update_pixels(0x000000)
    time.sleep(0.002)

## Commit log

2021-09-16 adding design & PCB files
    [HRO TYPE-C-31-M-12.step, KailhSocket.stp, LTST-A683CEGBW.step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]
2021-11-03 adding more connections
    [PyKey60.kicad_pcb, PyKey60.sch]
2021-11-04 Remove I2C and SPI due to space
    Not enough space to route additional columns; debugging should be ok via SWD.
    [PyKey60.kicad_pcb, PyKey60.sch]
2021-11-04 Move USB
    Move USB and update silkscreen info (name, source URL)
    [PyKey60.kicad_pcb]
2021-11-06 Update Schematic to Reflect PCB
    Also reroute +3.3V through 100nF capacitor before LED per https://optoelectronics.liteon.com/upload/download/DS35-2019-0032/LTST-A683CEGBW.PDF
    [PyKey60.kicad_pcb, PyKey60.sch]
2021-11-08 Reinstall LED and Speaker
    I decided I like knowing when caps lock is on and want to play Star Trek sounds on my keyboard.
    [PyKey60.kicad_pcb, PyKey60.sch]
2021-11-08 Generate Gerber.zip
    [PyKey60-B_Mask.gbs, PyKey60-B_Paste.gbp, PyKey60-B_SilkS.gbo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]
2021-11-08 Fix Footprints and Cap Names
    Renamed capacitors to correspond with keys (non-key caps shifted +87). Fixed rogue footprints to rotated hand-solder versions.
    [PyKey60.kicad_pcb]
2021-11-10 Add new mounting holes
    Also shift some traces to make it work
    [PyKey60.kicad_pcb]
2021-11-11 Reroute and round PCB
    [JLPCB-BOM.xlsx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]
2021-11-12 Add bottom plate and I2C
    [PyKey60.kicad_pcb, PyKey60.sch, PyKey87-bottom.kicad_pcb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]
2021-11-12 Add cutout for obscured switches
    Also added extra holes for feet and additional standoff
    [PyKey60.kicad_pcb, PyKey60.sch, PyKey87-bottom.kicad_pcb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]
2021-11-13 Shrink standoffs, enlarge cutout
    added an additional standoff near G/H
    [PyKey60.kicad_pcb, PyKey60.sch, PyKey87-bottom.kicad_pcb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]
2021-11-13 re-org and added folder for pykey87 (TKL!)
    [HRO TYPE-C-31-M-12.step, KailhSocket.stp, LTST-A683CEGBW.step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]
2021-11-13 Moving things around
    Prep for merging. Also did some clean up and added 8th standoff.
    [HRO TYPE-C-31-M-12.step, JLPCB-BOM.xlsx, KailhSocket.stp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]
2021-11-13 Added I2C header
    and 2nd tooling hole
    [PyKey87.kicad_pcb]
2021-11-14 Move boot/run and reset to edge
    Also cleanup, renaming, and adding a second I2C header.
    [PyKey87.kicad_pcb, PyKey87.sch]
2021-11-14 Working on issues
    https://github.com/jpconstantineau/PyKey60/issues/3
    [PyKey87-bottom.kicad_pcb, PyKey87-bottom.sch, PyKey87.kicad_pcb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]
2021-11-15 working on issue 2
    [PyKey87.kicad_pcb, PyKey87.sch]
2021-11-15 update title block
    [PyKey87.kicad_pcb]
2021-11-16 Add logo and copper plane
    [PyKey87-bottom.kicad_pcb]
2021-11-17 Initial upload of plate, fixing issues
    [PyKey87.kicad_pcb, PyKey87.sch, Switch-plate.kicad_pcb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]
2021-11-17 Move D87 for better fit
    [PyKey87.kicad_pcb, PyKey87.sch, Switch-plate.kicad_pcb]
2021-11-17 Moved R1 and R2 further from USB
    [PyKey87.kicad_pcb]
2021-11-18 Misc fixes to schematic, PCB, and plates
    [PyKey87-bottom.kicad_pcb, PyKey87.kicad_pcb, PyKey87.sch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]
2021-11-19 PyKey Schematic
    [HRO TYPE-C-31-M-12.step, KailhSocket.stp, LTST-A683CEGBW.step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]
2021-11-19 Moved Row0, and rotated stabilizers in plate
    [PyKey60-B_Mask.gbs, PyKey60-B_Paste.gbp, PyKey60-B_SilkS.gbo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]
2021-11-21 Generate production files
    [PyKey87-B_Mask.gbs, PyKey87-B_Paste.gbp, PyKey87-B_SilkS.gbo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]
2021-11-21 adding PyKey18 PCB
    [PyKey18.kicad_pcb, PyKey18.sch, PyKey60.kicad_pcb]
2021-11-22 Refill switch plate and generate gerbers
    [Switch-plate-B_Cu.gbl, Switch-plate-B_Mask.gbs, Switch-plate-B_Paste.gbp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]
2021-11-22 Attempting to fix merge issues
    [HRO TYPE-C-31-M-12.step, KailhSocket.stp, LTST-A683CEGBW.step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]
2021-11-23 minor updates and PyKey18 Bottom Plate
    [HRO TYPE-C-31-M-12.step, KailhSocket.stp, LTST-A683CEGBW.step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]
2021-11-23 addes RGB Caps
    [PyKey18-B_Cu.gbr, PyKey18-B_Mask.gbr, PyKey18-B_Paste.gbr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]
2021-11-24 add esd protection
    [PyKey18-B_Cu.gbr, PyKey18-B_Mask.gbr, PyKey18-B_Paste.gbr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]
2021-12-08 Move "Reset" closer to button, add non-logo bottom plate
    [PyKey87-bottom-B_Cu.gbl, PyKey87-bottom-B_Mask.gbs, PyKey87-bottom-B_Paste.gbp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]
2021-12-15 Fix for D81-D83 in way of hot-swap socket
    [PyKey87.kicad_pcb]
2022-02-04 updates to traces
    [PyKey87-B_Mask.gbs, PyKey87-B_Paste.gbp, PyKey87-B_SilkS.gbo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]
2023-01-27 added firmware to copy to circuitpython drive

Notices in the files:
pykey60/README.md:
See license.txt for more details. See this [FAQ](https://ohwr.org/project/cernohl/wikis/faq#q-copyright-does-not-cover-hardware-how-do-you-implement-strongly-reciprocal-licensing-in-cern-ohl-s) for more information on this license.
